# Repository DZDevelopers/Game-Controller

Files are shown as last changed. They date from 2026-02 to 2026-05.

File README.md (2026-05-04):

# Game Controller

This is a game controller powered by an Arduino Nano RP2040. It features two joysticks and ten buttons, designed for custom gaming and input projects.

This project is fully open-source and includes schematics, PCB design, and a simple enclosure.
### Overall game controller
image (1)

### Schematic


### PCB


## Hardware Overview

Microcontroller: Arduino Micro RP2040

Buttons: Push Button Switch

joysticks: COM-09032

## Bill of Materials (BOM)

1 x Raspberry Pi Pico

10 x Push Button Switch

2 x COM-09032

1 × Custom-designed PCB

1 × Case (3D-printed)

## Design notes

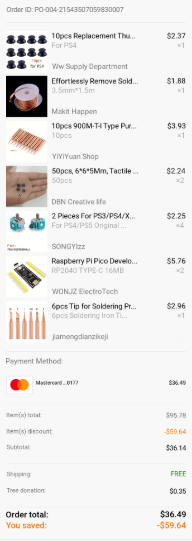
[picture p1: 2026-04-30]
unnamed.png

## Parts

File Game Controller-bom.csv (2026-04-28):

Name | Purpose | Quantity | Total Cost (USD) | Link | Distributor
solder flux | Its flex it helps solder stick to stuff | 1 | 4.00 | https://ar.aliexpress.com/item/1005008459768970.html?curPageLogUid=YRy7BN9yp5nG | Aliexpress
Thumbsticks | It's so the control will actualy be useable | 1 | 2.50 | https://www.temu.com/goods.html?goods_id=601102485459414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 | Temu
Solder Wick | To absorb solder | 1 | 2.00 | https://www.temu.com/goods.html?goods_id=601099549740217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 | Temu
Soldering Iron Tip | All my tips got oxidized and aren't conducting heat anymore | 1 | 4.00 | https://www.temu.com/dz-en/10pcs--t-i-type-pure-copper-soldering-iron-tip-replacement-soldering-iron-tip-set-for--station-tools-g-601099679613463.html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 | Temu
MCP3008 | the pico pi doesnt have enough adc | 1 | 2.75 | https://ar.aliexpress.com/item/1005006649507949.html?curPageLogUid=KSzUQSvsDYc7 | Aliexpress
Custom-designed PCB |  | 1 | 1.00 |  | aivon
Push Button Switch |  | 10 | 2.25 | https://www.temu.com/dz-en/50pcs-6-6-5mm-tactile--pin-push-button-g-601099520633185.html?spec_gallery_id=999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 | Temu
COM-09032 |  | 2 | 5.50 | https://www.temu.com/dz-en/2-pieces-for-ps3-ps4--360-one-game-controller-3d-joystick-ps5-3d-joystick-repair-accessories-g-601099529501202.html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 | Temu
Raspberry Pi Pico |  | 1 | 5.50 | https://www.temu.com/dz-en/-pico-development-board---264kb-arm--m0-mcu-low-power--compatible-with-csdk-g-601099678816052.html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 | Temu
3D Printed Case |  | 1 | 5.00

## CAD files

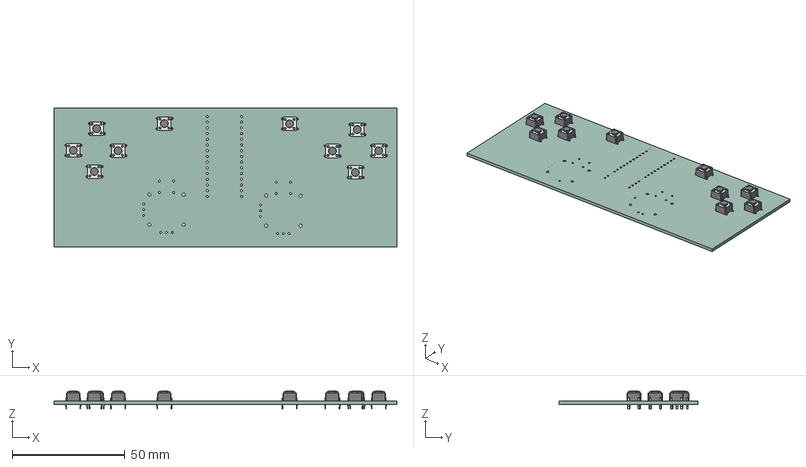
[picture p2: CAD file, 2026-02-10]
CAD/GameController.step
152.4 x 61.9 x 7.80 mm
SW_PUSH_6mm x 10
GameController_PCB

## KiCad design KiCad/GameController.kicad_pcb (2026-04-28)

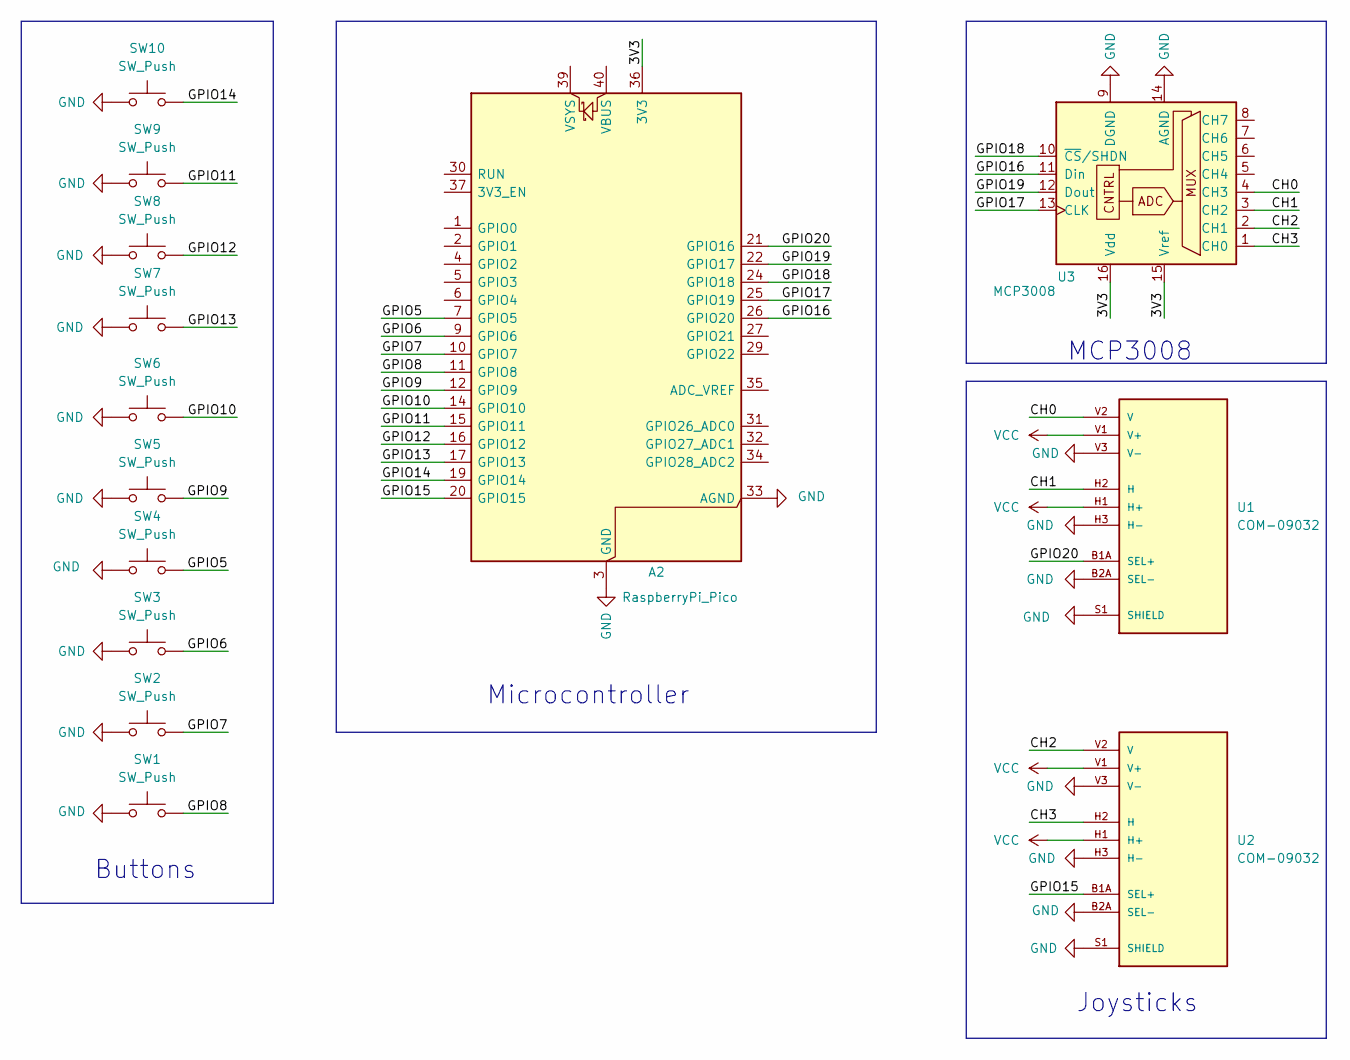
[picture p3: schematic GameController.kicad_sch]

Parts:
A2: RaspberryPi_Pico; RaspberryPi_Pico_Common_THT
SW1, SW2, SW3, SW4, SW5, SW6, SW7, SW8, SW9, SW10: SW_Push; SW_PUSH_6mm
U1, U2: COM-09032; XDCR_COM-09032; PARTREV N/A
U3: MCP3008; DIP-16_W7.62mm

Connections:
/3V3: A2.36 (3V3), U3.15 (Vref), U3.16 (Vdd)
/CH0: U1.V2 (V), U3.4 (CH3)
/CH1: U1.H2 (H), U3.3 (CH2)
/CH2: U2.V2 (V), U3.2 (CH1)
/CH3: U2.H2 (H), U3.1 (CH0)
/GPIO5: A2.7 (GPIO5), SW4.2
/GPIO6: A2.9 (GPIO6), SW3.2
/GPIO7: A2.10 (GPIO7), SW2.2
/GPIO8: A2.11 (GPIO8), SW1.2
/GPIO9: A2.12 (GPIO9), SW5.2
/GPIO10: A2.14 (GPIO10), SW6.2
/GPIO11: A2.15 (GPIO11), SW9.2
/GPIO12: A2.16 (GPIO12), SW8.2
/GPIO13: A2.17 (GPIO13), SW7.2
/GPIO14: A2.19 (GPIO14), SW10.2
/GPIO15: A2.20 (GPIO15), U2.B1A (SEL+)
/GPIO16: A2.26 (GPIO20), U3.11 (Din)
/GPIO17: A2.25 (GPIO19), U3.13 (CLK)
/GPIO18: A2.24 (GPIO18), U3.10 (~CS/SHDN)
/GPIO19: A2.22 (GPIO17), U3.12 (Dout)
/GPIO20: A2.21 (GPIO16), U1.B1A (SEL+)
GND: A2.3 (GND), A2.8 (GND), A2.13 (GND), A2.18 (GND), A2.23 (GND), A2.28 (GND), A2.33 (AGND), A2.38 (GND), SW1.1, SW2.1, SW3.1, SW4.1, SW5.1, SW6.1, SW7.1, SW8.1, SW9.1, SW10.1, U1.B2A (SEL-), U1.H3 (H-), U1.S1 (SHIELD), U1.S2 (SHIELD), U1.S3 (SHIELD), U1.S4 (SHIELD), U1.V3 (V-), U2.B2A (SEL-), U2.H3 (H-), U2.S1 (SHIELD), U2.S2 (SHIELD), U2.S3 (SHIELD), U2.S4 (SHIELD), U2.V3 (V-), U3.9 (DGND), U3.14 (AGND)
VCC: U1.H1 (H+), U1.V1 (V+), U2.H1 (H+), U2.V1 (V+)

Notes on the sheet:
Microcontroller
Buttons
MCP3008
Joysticks

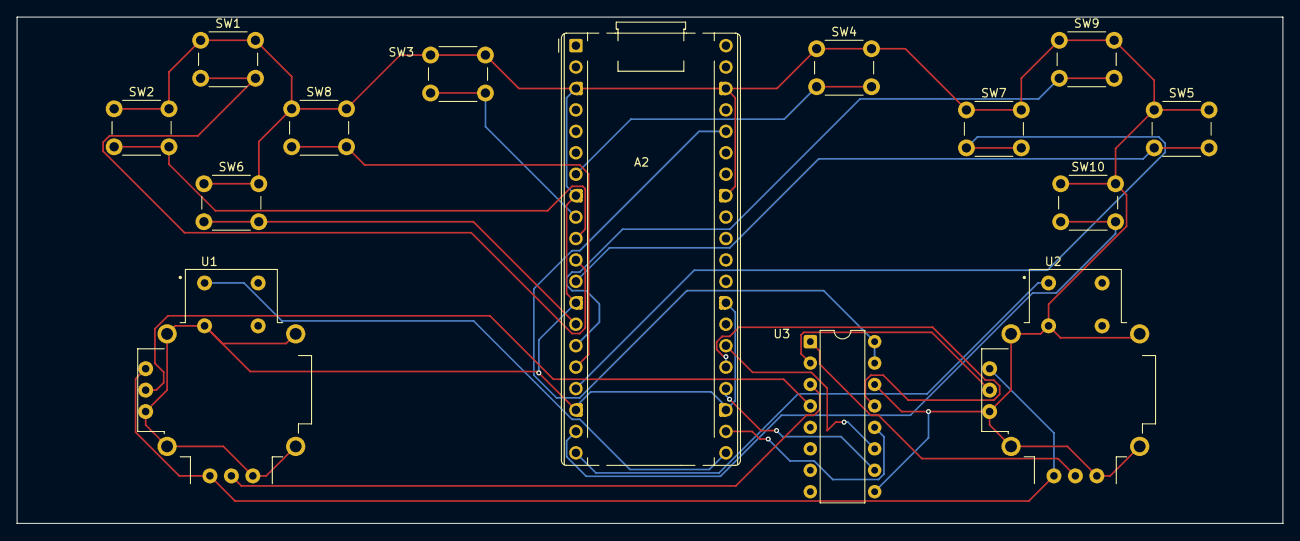
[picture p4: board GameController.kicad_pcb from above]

Board: 2 copper layers, 150.0 x 60.0 mm, 14 parts (0 on the bottom side), 23 nets.

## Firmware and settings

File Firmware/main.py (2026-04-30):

from machine import Pin, SPI
import utime
import ujson

# buttons - all wired GND -> switch -> pin, so pressed = LOW
# SW1 through SW10 in order
btn_pins = [8, 7, 5, 6, 9, 10, 13, 12, 11, 14]
buttons = [Pin(p, Pin.IN, Pin.PULL_UP) for p in btn_pins]

# joystick click buttons
joy1_btn = Pin(20, Pin.IN, Pin.PULL_UP)
joy2_btn = Pin(15, Pin.IN, Pin.PULL_UP)

# MCP3008 on SPI0
# MISO=16, SCK=17, CS=18, MOSI=19
spi = SPI(0, baudrate=1000000, polarity=0, phase=0,
          sck=Pin(17), mosi=Pin(19), miso=Pin(16))
cs = Pin(18, Pin.OUT, value=1)

def read_adc(ch):
    # standard MCP3008 single-ended read
    buf = bytearray(3)
    cmd = bytearray([0x01, 0x80 | (ch << 4), 0x00])
    cs(0)
    spi.write_readinto(cmd, buf)
    cs(1)
    return ((buf[1] & 0x03) << 8) | buf[2]

# simple debounce - track last stable state + when it changed
last_state = [1] * len(buttons)
last_change = [0] * len(buttons)
DEBOUNCE = 20  # ms

def get_buttons():
    now = utime.ticks_ms()
    result = []
    for i, b in enumerate(buttons):
        v = b.value()
        if v != last_state[i] and utime.ticks_diff(now, last_change[i]) > DEBOUNCE:
            last_state[i] = v
            last_change[i] = now
        result.append(0 if last_state[i] else 1)  # invert: pressed=1
    return result

def get_joy(x_ch, y_ch, btn):
    return [read_adc(x_ch), read_adc(y_ch), 0 if btn.value() else 1]

print("# ready")

while True:
    t = utime.ticks_ms()

    btns = get_buttons()
    j1 = get_joy(1, 0, joy1_btn)   # CH1=X, CH0=Y
    j2 = get_joy(3, 2, joy2_btn)   # CH3=X, CH2=Y

    print(ujson.dumps({"b": btns, "j1": j1, "j2": j2}))

    # try to keep ~100hz, account for how long the reads took
    elapsed = utime.ticks_diff(utime.ticks_ms(), t)
    if elapsed < 10:
        utime.sleep_ms(10 - elapsed)

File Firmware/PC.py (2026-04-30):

import json, time, sys, argparse
import serial
import serial.tools.list_ports

def find_pico():
    for p in serial.tools.list_ports.comports():
        if p.vid == 0x2E8A:  # raspberry pi
            return p.device
    return None

def scale(raw, dz=20):
    v = raw - 512
    if abs(v) < dz:
        return 0.0
    s = 1 if v > 0 else -1
    return round(s * min((abs(v) - dz) / (512 - dz), 1.0), 3)

def dashboard(ser):
    btn_names = [f"SW{i+1}" for i in range(10)]
    print("\033[2J\033[H", end="")
    while True:
        try:
            line = ser.readline().decode().strip()
            if not line or line.startswith("#"):
                continue
            d = json.loads(line)
            b  = d["b"]
            j1 = d["j1"]
            j2 = d["j2"]

            print("\033[H", end="")
            print("Pico Gamepad\n")

            print("Buttons:")
            for i, (name, state) in enumerate(zip(btn_names, b)):
                print(f"  {name}: {'ON ' if state else 'off'}", end="")
                if (i + 1) % 5 == 0:
                    print()
            print()

            print(f"\nJoy1  x={scale(j1[0]):+.2f}  y={scale(j1[1]):+.2f}  btn={'ON' if j1[2] else 'off'}")
            print(f"Joy2  x={scale(j2[0]):+.2f}  y={scale(j2[1]):+.2f}  btn={'ON' if j2[2] else 'off'}")
            print("\nctrl+c to quit")

        except (json.JSONDecodeError, KeyError):
            pass
        except KeyboardInterrupt:
            break

def hid_bridge(ser):
    try:
        import vgamepad as vg
    except ImportError:
        print("pip install vgamepad first")
        sys.exit(1)

    pad = vg.VX360Gamepad()
    print("virtual gamepad active")

    btn_map = [
        vg.XUSB_BUTTON.XUSB_GAMEPAD_A,
        vg.XUSB_BUTTON.XUSB_GAMEPAD_B,
        vg.XUSB_BUTTON.XUSB_GAMEPAD_X,
        vg.XUSB_BUTTON.XUSB_GAMEPAD_Y,
        vg.XUSB_BUTTON.XUSB_GAMEPAD_LEFT_SHOULDER,
        vg.XUSB_BUTTON.XUSB_GAMEPAD_RIGHT_SHOULDER,
        vg.XUSB_BUTTON.XUSB_GAMEPAD_BACK,
        vg.XUSB_BUTTON.XUSB_GAMEPAD_START,
        vg.XUSB_BUTTON.XUSB_GAMEPAD_DPAD_UP,
        vg.XUSB_BUTTON.XUSB_GAMEPAD_DPAD_DOWN,
    ]

    while True:
        try:
            line = ser.readline().decode().strip()
            if not line or line.startswith("#"):
                continue
            d = json.loads(line)
            b  = d["b"]
            j1 = d["j1"]
            j2 = d["j2"]

            pad.reset()
            for state, btn in zip(b, btn_map):
                if state:
                    pad.press_button(btn)
            if j1[2]:
                pad.press_button(vg.XUSB_BUTTON.XUSB_GAMEPAD_LEFT_THUMB)
            if j2[2]:
                pad.press_button(vg.XUSB_BUTTON.XUSB_GAMEPAD_RIGHT_THUMB)

            pad.left_joystick(x_value_float=scale(j1[0]), y_value_float=-scale(j1[1]))
            pad.right_joystick(x_value_float=scale(j2[0]), y_value_float=-scale(j2[1]))
            pad.update()

        except (json.JSONDecodeError, KeyError):
            pass
        except KeyboardInterrupt:
            break

if __name__ == "__main__":
    ap = argparse.ArgumentParser()
    ap.add_argument("--port")
    ap.add_argument("--hid", action="store_true")
    args = ap.parse_args()

    port = args.port or find_pico()
    if not port:
        print("couldn't find pico, use --port")
        sys.exit(1)

    print(f"connecting to {port}...")
    with serial.Serial(port, 115200, timeout=1) as ser:
        time.sleep(0.5)
        ser.reset_input_buffer()
        hid_bridge(ser) if args.hid else dashboard(ser)
